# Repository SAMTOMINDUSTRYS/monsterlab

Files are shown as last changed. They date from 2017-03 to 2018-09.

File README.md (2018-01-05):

# Monster Lab
### We sequence monsters.

In 2017, we built a Lego DNA sequencer to teach kids about DNA, Sequencing and Phenotypes. 
[Our imgur album](http://imgur.com/gallery/4O8r4) gives a reasonable construction tutorial. For more information on the **Monster Lab** activity itself, you can read [this blog post](https://samnicholls.net/2017/03/15/lego-sequencer/).

### Can I use this for public engagement?
Yes! Our activity is open-source and we'd love you to use it. This repository contains (almost) everything you would need to construct your own Lego sequencer and run our Monster Lab activity.

* `laser\`: Contains DXF formatted files for the laser cut parts, including the base plate, Lego tray and gear to attach to the stepper. The 3mm and 6mm refers to the thickness of the acrylic used to cut those parts for our model.
* `wiring\`: Contains a Fritzing diagram for wiring the Arduino Uno, EasyDriver and RGB Colour Sensor. Note that we had to flip the inner pair of wires from our stepper motor but this may differ for yours. [This hook-up guide](https://learn.sparkfun.com/tutorials/easy-driver-hook-up-guide) gives more information on checking the coils of your stepper and how to wire it up.
* `software\`: The current version of the `ino` to compile and upload to the Uno.
* `paperwork\`: Contains blank and example monster record sheets and gene lists (feel free to use the example from our iteration of the activity at 2017 Science Week)

## Housekeeping
### Licenses
The components of **Monster Lab** are open-source under the following licenses.

* Monster Lab software (`software\`) is made available under the MIT License.
* Our designs for use with a laser cutter or 3D printer are licensed under a Creative Commons Attribution 4.0 International License.
* Blank forms (`paperwork\`) are licensed under a Creative Commons Attribution 4.0 International License.

Although you are not obligated by these licenses to credit us, **Monster Lab** was hard work that we aren't paid for, so we ask that you kindly attempt to credit us as the original authors of the idea where you can; such as a link to us in a blog post of your event, or some shout-outs to `@samstudio8` and `@monsterdnalab` during your event on Twitter.

We'd love to know if you've run your own **Monster Lab**, and link to your write-up or photo gallery, so please [submit an issue](https://github.com/samtomindustrys/monsterlab/issues) or pull request against the list below!

## Monster Labs
* Aberystwyth University Science Week 2017 - [Blog Post](https://samnicholls.net/2017/03/15/lego-sequencer/) - [https://monster-lab.org/](https://monster-lab.org/)

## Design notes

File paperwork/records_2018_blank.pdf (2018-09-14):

# SAM&TOMINDUSTRYS:AULAB:01

OCU1 | OCU2 | MEM1 | MEM2 | FRM1 | FRM2 | MAG1 | PAT10 | DWF7 | SPEC
Scientist Name | School | Date
18

## Monster Genome Record

# SAM&TOMINDUSTRYS:AULAB:01

18LAMP01

Sequencing Unit | Reagent Batch | Lab Stamp

# SAM&TOMINDUSTRYS:AULAB:01

OCU1 | OCU2 | MEM1 | MEM2 | FRM1 | FRM2 | MAG1 | PAT10 | DWF7 | SPEC
Scientist Name | School | Date
18

## Monster Genome Record

# SAM&TOMINDUSTRYS:AULAB:01

18LAMP01

Sequencing Unit | Reagent Batch | Lab Stamp
v1.1 | v1.1

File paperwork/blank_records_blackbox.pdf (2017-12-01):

SAM&TOMINDUSTRYS:AULAB:01

Scientist Name | School | Date

Monster Genome Record

SAM&TOMINDUSTRYS:AULAB:01

Sequencing Unit | Reagent Batch | Lab Stamp

SAM&TOMINDUSTRYS:AULAB:01

Scientist Name | School | Date

Monster Genome Record

SAM&TOMINDUSTRYS:AULAB:01

Sequencing Unit | Reagent Batch | Lab Stamp
v1.1 | v1.1

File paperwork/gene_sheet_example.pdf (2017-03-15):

# SAM&TOMINDUSTRYS:AULAB:01

# Monster Gene Datasheet

# SAM&TOMINDUSTRYS:AULAB:01

170315-V1.1

| Description | Base | Result (Phenotype)
OCU1 | A 1 Eye Number of Eyes
C 2 Eyes G

T 8 Eyes

OCU2 Eye Colour

A Blue
C Green
G Brown
T Random

MEM1 Number of Legs

A 2 Legs
C 4 Legs G

T 8 Legs

MEM2 Appendages or Extremities

A Wings
C Antennae
G Horns
T Tail

FRM1 Monster Type

A Grass
C Electric
G Fire
T Water

FRM2 Skin Type

A Fur
C Feathers
G Scales
T Shell

MAG1 Monster Size

A Tiny
C Large
G Small
T Monstrous

PAT10 Colour Pattern

A Spots
C Stripes
G Patches T

DWF7 Temperament (Mood)

A Happy
C Grumpy
G Sleepy
T Bashful

SPEC Special Power

A Super speed
C Freeze blast
G Breathes underwater
T Breathes fire

UV-010-01

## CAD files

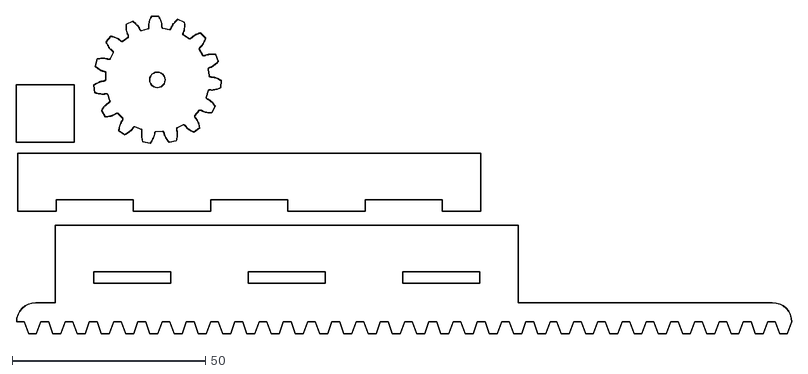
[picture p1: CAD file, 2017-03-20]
laser/sled_sides_and_gears.dxf
200.9 x 82.3

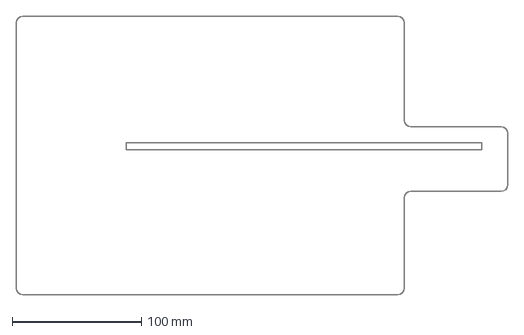
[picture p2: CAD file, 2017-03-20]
laser/base.dxf
380.0 x 215.0 mm

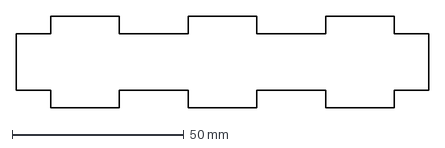
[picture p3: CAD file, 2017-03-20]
laser/parts_acrylic_3mm.dxf
120.0 x 26.5 mm

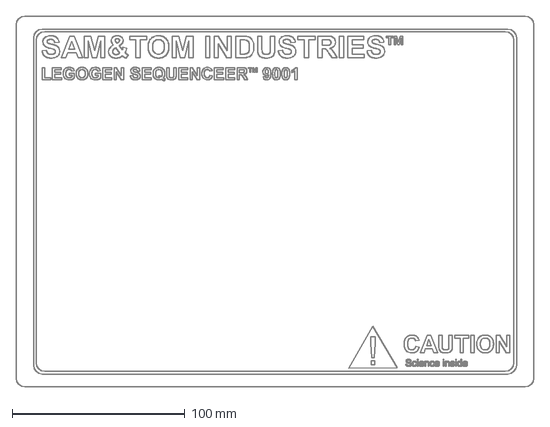
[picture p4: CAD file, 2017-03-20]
laser/lid.dxf
300.0 x 215.0 mm

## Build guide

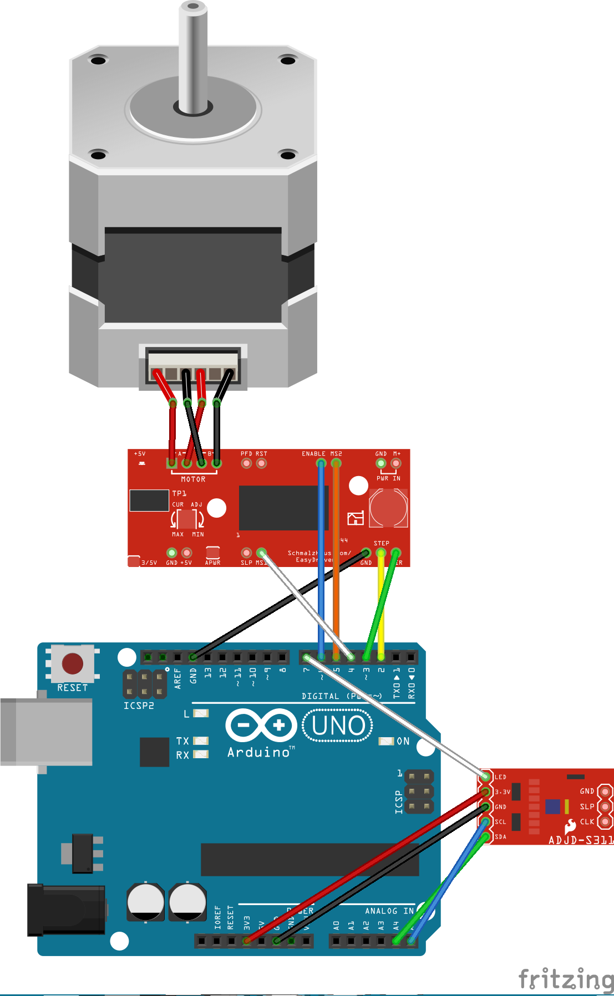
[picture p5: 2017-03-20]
wiring/seq_wiring.png

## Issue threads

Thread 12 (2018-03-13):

Nice power supply system needed

tomblanch118, 2018-03-13:
We really need/want a better power supply system. Ideally take 12V in (need at least a few amps for the stepper motors peak draw) and step down to 5V and 3.3V for various other systems. If we are going to be using RGB LEDs and/or Raspberry Pis in the future we would need a much beefier 5V rail.

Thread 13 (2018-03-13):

Stepper Issues

tomblanch118, 2018-03-13:
Low power stepper driver - https://www.pololu.com/product/2134/specs

Might be able to move to a low voltage stepper (5V) simplify power issues?

Manually driving a stepper using a a4988 I was able to get a reasonable slow speed performance but it was a 0.9 degree per step motor

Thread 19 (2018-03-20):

The margins are still wrong

SamStudio8, 2018-03-20:
i have dumb dumb'd again
the left/right margins on the gene records are still wrong because most printers don't print-to-edge

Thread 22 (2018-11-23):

Document colour encoding (bases for red, green, yellow and blue)

peterjc, 2018-11-23:
The rival project *Blocksford Brickopore LEGO sequencer* uses red (“T”), green (“A”), yellow (“G”) and blue (“C”) LEGO bricks - as documented here:

http://www.earlham.ac.uk/articles/earlham-institute-lego-sequencer

My immediate concern was did they invent a new encoding (I'm having FASTQ flashbacks here)?

Sadly it seems yes, since according to https://samnicholls.net/2017/03/15/lego-sequencer/ you used blue for "T".

Further digging, https://imgur.com/gallery/4O8r4 says "*It would later turn out that we could distinguish yellow using the Clear channel, as it is much more reflective these values dwarf the rest of the values. Red, blue and green can easily be distinguished by checking the which of the RGB channels is currently giving the highest reading.*"

I could find the relevant part of your code here, mapping an RGB and Clear value to DNA base letters:

https://github.com/SAMTOMINDUSTRYS/monsterlab/blob/master/software/samseq.ino#L132

```
  if(clear > 10000){
    Serial.print("C");
  }
  else {
    if(green > blue && green > red){
        Serial.print("A");
    }
    else if(red > green && red > blue){
        Serial.print("G");
    }
    else if(blue > green){
        Serial.print("T");
    }
    else{
        Serial.print("N");
    }
  }
```

I think that means yellow "C", green "A", red "G", blue "T", other "N".

(On a more serious note, I presume the printed sheets etc deliberately do not give away the colour key so as not to spoil the surprise)

SamStudio8, 2018-11-23:
I _think_ we took our colour codings from the ones used by `Tablet`, but we should make a note of them in the README somewhere. Though you're right, the monster sheets are intended to not provide a key to prevent kids gaming the system! Although, at future workshops we'll probably get participants to look at the Monster Lab Zoo and see what bases encode what phenotype.

peterjc, 2018-11-23:
Yes, the colour scheme does seem to match Tablet having checked a couple of screenshots:
https://ics.hutton.ac.uk/tablet/tablet-screenshots/

I expect @imilne would be able to tell us where that scheme originally came from (as I assume it followed an even older convention).

gringer, 2018-11-23:
The convention for electrophoresis colours, as used in trace plots, is red (“T”), green (“A”), yellow (“G”) and blue (“C”), e.g. see [here](https://www.softgenetics.com/mutationSurveyor_2.php). This is the closest to a DNA colour convention that I have found, and what I prefer to use in all my code.

peterjc, 2018-11-23:
Chromas (which is the oldest Sanger capillary sequencing tool I've used) does red "T", green "A", black "G" and blue "C" http://technelysium.com.au/wp/chromas/ - which with apparently common yellow/black substitution matches Blocksford Brickopore LEGO sequencer.

I wonder if we can find some early references for precedents establishing these kinds of convention? Might even make a nice short review paper somewhere, if no one has done that already?

peterjc, 2018-11-23:
From the original JalView documentation they describe various protein colour schemes:
http://www.jalview.org/version118/documentation.html#colour

peterjc, 2018-11-23:
BioEdit screenshots here:
http://www.mbio.ncsu.edu/BioEdit/screenshots.html

Again, red "T" or "U", green "A", black "G" and blue "C"

gringer, 2018-11-26:
After 1986, anyway. ABI used A:Fluorescein / FITC (520nm; green emission), T:NBD (550nm; green/yellow emission), G:Tetramethylrhodamine (580nm; yellow emission) and C:Texas Red (610nm; orange emission) in what looks like it could be their first fluorescence sequencing paper:

https://doi.org/10.1038/321674a0

Deep blue was avoided at the time because of the potential for scattering and overlap with fluorescence background (according to the paper). It seems like that unease has since been overcome.

peterjc, 2018-11-26:
Using red, green, greeny-yellow, and yellow Lego blocks just wouldn't have the same visual impact (and would be more expensive to source too). Blue is better :)

peterjc, 2018-11-26:
Update from Jim Proctor (@foreveremain on GitHub) on Twitter https://twitter.com/foreveremain/status/1067076249745539072 saying:

> AM Waterhouse created Jalview's nucleotide colours in Jan 2005, based on TOPALi's topali.org - so best ask Frank Wright and Iain Milne ;) FWIW see other schemes in Figure 2 of nature.com/articles/nmeth… (paywalled but figure is visible)

Here is Figure 2(c) from https://doi.org/10.1038/nmeth.1434 Proctor *et al.* (2010)

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

Amusingly none of the four schemes shown using four colours for the four different bases matches the ABI electrophoresis/gel colours.

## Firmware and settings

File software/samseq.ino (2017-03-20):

#include <Adafruit_TCS34725.h>

/* Connect SCL    to analog 5
   Connect SDA    to analog 4
   Connect VDD    to 3.3V DC
   Connect GROUND to common ground */

#define ledpin 7

Adafruit_TCS34725 tcs = Adafruit_TCS34725(TCS34725_INTEGRATIONTIME_50MS, TCS34725_GAIN_4X);

#define stp 2
#define dir 3
#define MS1 4
#define MS2 5
#define EN  6

int BLOCK_STEP = 165;
int INIT_STEP = 350;
int NUM_BLOCKS = 10;
int REVERSE_STEP = ((NUM_BLOCKS-1) * BLOCK_STEP) + INIT_STEP;

int state;
int x;
int y;

char* genes[]={
  "OCU1",
  "OCU2",
  "MEM1",
  "MEM2",
  "FRM1",
  "FRM2",
  "MAG1",
  "PAT10",
  "DWF7",
  "SPEC"
};

void setup() {
  Serial.begin(9600); //Open Serial connection for debugging

  // Setup motor
  pinMode(stp, OUTPUT);
  pinMode(dir, OUTPUT);
  pinMode(MS1, OUTPUT);
  pinMode(MS2, OUTPUT);
  pinMode(EN, OUTPUT);
  pinMode(ledpin, OUTPUT);
  resetEDPins(); //Set step, direction, microstep and enable pins to default states

  if (tcs.begin()) {
  } else {
    Serial.println("No TCS34725 found ... check your connections");
    while (1); // halt!
  }

  // LED off to prevent overheating
  digitalWrite(ledpin, LOW);

  digitalWrite(EN, LOW); // Enable motor
  digitalWrite(dir, LOW); // Forward motor
  digitalWrite(MS1, HIGH); //Pull MS1, and MS2 high to set logic to 1/8th microstep resolution
  digitalWrite(MS2, HIGH);
  for (x = 1; x < INIT_STEP; x++) {
    digitalWrite(stp, HIGH); //Trigger one step forward
    delay(1);
    digitalWrite(stp, LOW); //Pull step pin low so it can be triggered again
    delay(1);
  }

  delay(1000);
  digitalWrite(dir, LOW); // Forward motor
  digitalWrite(MS1, HIGH); //Pull MS1, and MS2 high to set logic to 1/8th microstep resolution
  digitalWrite(MS2, HIGH);

  do_sequence();
}

void eject() {
  // LED off
  digitalWrite(ledpin, LOW);
  digitalWrite(dir, HIGH); // Reverse motor
  delay(500);
  digitalWrite(MS1, HIGH); //Pull MS1, and MS2 high to set logic to 1/8th microstep resolution
  digitalWrite(MS2, HIGH);
  for (x = 1; x < REVERSE_STEP; x++) {
    digitalWrite(stp, HIGH);
    delay(1);
    digitalWrite(stp, LOW);
    delay(1);
  }
  //digitalWrite(EN, HIGH); // Disable motor
}

void do_sequence() {
  Serial.println("C\tR\tG\tB\tGene\tBase");
  Serial.println("--------------------------------------------");
  digitalWrite(ledpin, HIGH); // LED on
  digitalWrite(EN, LOW); // Enable motor
  digitalWrite(dir, LOW); // Forward motor
  digitalWrite(MS1, HIGH); //Pull MS1, and MS2 high to set logic to 1/8th microstep resolution
  digitalWrite(MS2, HIGH);
  sequence_base(0); //First base
  for (y = 1; y < NUM_BLOCKS; y++) {
    for (x = 1; x < BLOCK_STEP; x++) {
      digitalWrite(stp, HIGH); //Trigger one step forward
      delay(1);
      digitalWrite(stp, LOW); //Pull step pin low so it can be triggered again
      delay(1);
    }
    delay(500);
    sequence_base(y);
  }
  eject();
}

void sequence_base(int gene_i) {
  uint16_t clear, red, green, blue;
  tcs.setInterrupt(false);      // turn on LED

  delay(60);  // takes 50ms to read
  tcs.getRawData(&red, &green, &blue, &clear);
  tcs.setInterrupt(true);  // turn off LED
  
  Serial.print(clear);
  Serial.print("\t"); Serial.print(red);
  Serial.print("\t"); Serial.print(green);
  Serial.print("\t"); Serial.print(blue);
  Serial.print("\t"); Serial.print(genes[gene_i]);
  Serial.print("\t");
  if(clear > 10000){
    Serial.print("C");
  }
  else {
    if(green > blue && green > red){
        Serial.print("A");
    }
    else if(red > green && red > blue){
        Serial.print("G");
    }
    else if(blue > green){
        Serial.print("T");
    }
    else{
        Serial.print("N");
    }
  }
  Serial.println();

}

//Main loop
void loop() {

}

//Reset Easy Driver pins to default states
void resetEDPins()
{
  digitalWrite(stp, LOW);
  digitalWrite(dir, LOW);
  digitalWrite(MS1, LOW);
  digitalWrite(MS2, LOW);
  digitalWrite(EN, HIGH);
}

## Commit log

2017-03-20 Add DXFs
    [gears_3mm.dxf, gears_6mm.dxf, lid.dxf]
2017-03-20 Added laser cutting dxfs
    Added dxfs for laser cut parts
    [base.dxf, gears_3mm.dxf, gears_6mm.dxf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]
2017-03-20 filename fix
    [sled_sides_and_gears.dxf]
